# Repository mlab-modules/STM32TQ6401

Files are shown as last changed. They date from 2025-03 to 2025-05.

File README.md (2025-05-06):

# STM32TQ6401 - Universal TQFP64 STM32 Microcontroller Module

The STM32TQ6401 is a universal microcontroller module designed for STM32 MCUs in TQFP64 packages. It offers a flexible platform for both development and deployment, with support for a wide range of STM32 devices and power configurations.

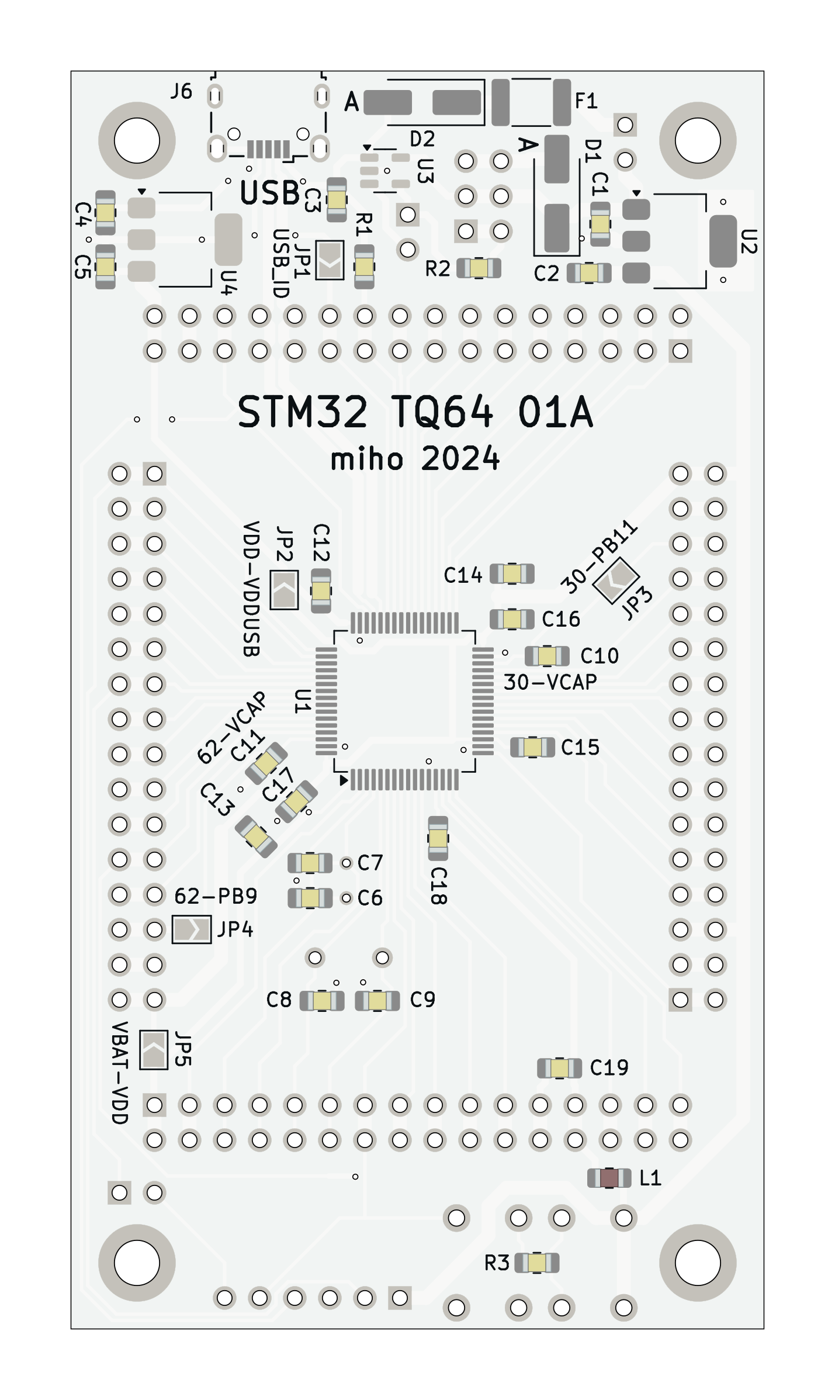
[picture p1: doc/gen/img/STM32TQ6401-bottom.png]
STM32TQ6401 module bottom

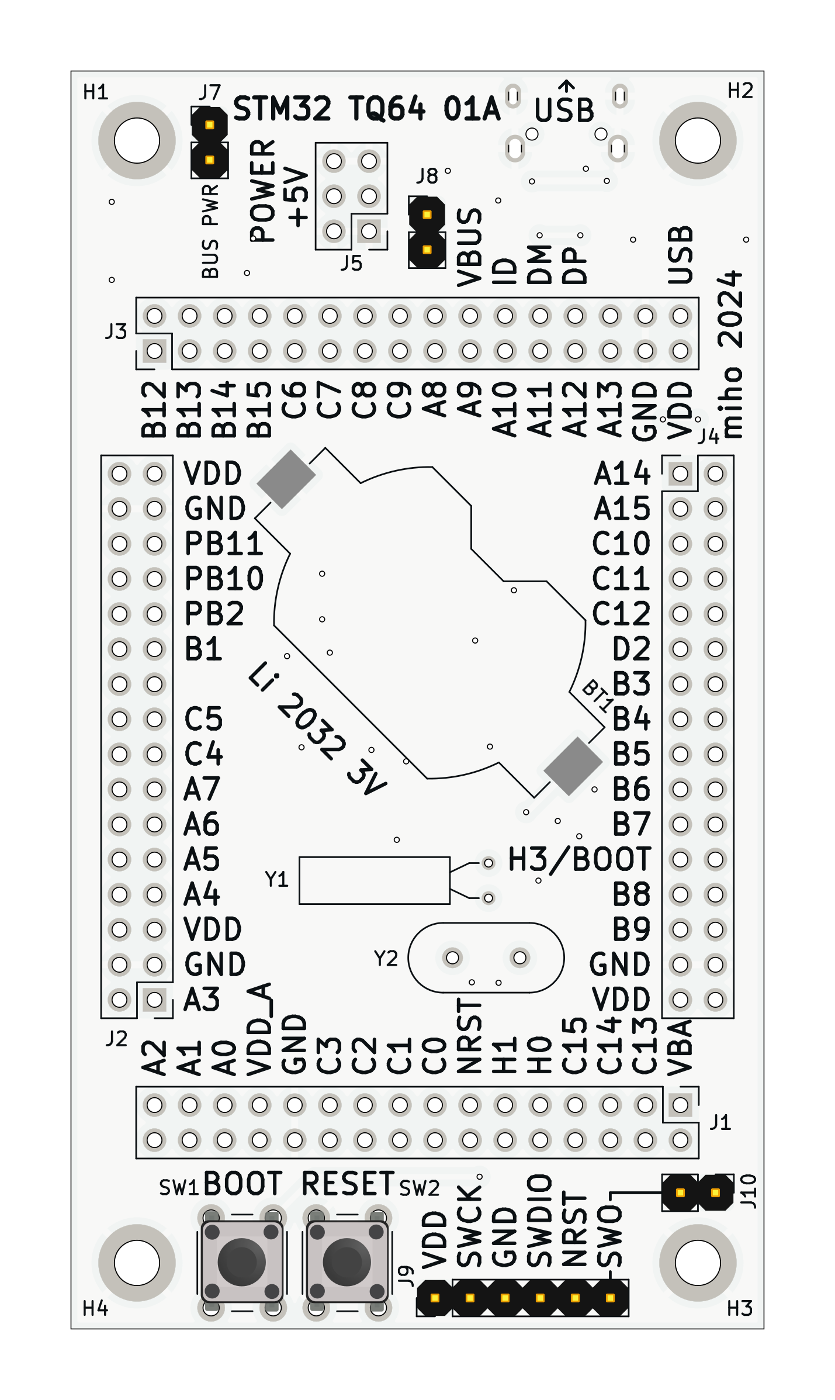
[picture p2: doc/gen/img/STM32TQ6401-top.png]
STM32TQ6401 module top


## Features

- Compatible with most STM32 MCUs in TQFP64 package (see note in schematics for exceptions)
- Direct battery operation from a CR2032 cell
- USB-C connector for both programming and external power input
- Standard MLAB pin headers for module interconnection to other MLAB modules
- Onboard 32.768 kHz and 16 MHz crystal oscillators for RTC and system clock
- Multiple LDO regulators providing 3.3V from USB or external 5V input
- USB power switch (TPS2051B) for host/device support
- Boot and reset buttons, debug header (SWD), and optional VCAP configuration

## Power Supply

- **Battery Operation:** Directly powered by a CR2032 cell; suitable for ultra-low power STM32 MCUs
- **USB Power:** Supplied through USB-C connector; LDO regulator converts 5V to 3.3V
- **External Power Input:** 2.6 V to 5.2 V via dedicated jumper or header

## Connectivity

- USB-C for firmware upload and serial communication
- SWD (Serial Wire Debug) header for in-circuit debugging
- MLAB standard headers for full I/O access

## Clock Sources

- **Y1:** 32.768 kHz crystal for RTC
- **Y2:** 16 MHz crystal for system clock

### Incompatible STM32 Devices
Some STM32 MCUs are not compatible with this module due to VCAP or other special pin requirements. These include (but are not limited to):

- STM32F030R4Tx, STM32F405RGTx, STM32H7xxRxTx
- STM32G4xxRxTx, STM32L5xxRxTxQ, STM32U5xxRxTxQ

Refer to schematic details for a complete list of incompatible devices.

### Pin Variants

Special attention is required for the following pins due to variant functions:

- VBAT / VLCD
- VCAP / VDDUSB
- BOOT0 / PH3

Refer to MCU datasheets and the module schematic for proper configuration.

## Mounting

- Four 3mm MLAB mounting holes for mechanical stability

## Schematic

For detailed pinout, power configuration, and compatibility, refer to the [STM32TQ6401A schematic](/doc/gen/STM32TQ6401-schematic.pdf).

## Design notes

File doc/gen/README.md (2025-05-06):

# PCB

Board size: 50.29x91.19 mm (1.98x3.59 inches)

- This is the size of the rectangle that contains the board
- Thickness: 1.6 mm (63 mils)
- Material: FR4
- Finish: HAL lead-free
- Layers: 2
- Copper thickness: 35 µm

Solder mask: TOP / BOTTOM

- Color: Green

Silk screen: TOP / BOTTOM

- Color: White

Stackup:

| Name | Type | Color | Thickness [µm]| Material | Er | Loss tan |
|---|---|---|---|---|---|---|
| F.SilkS | Top Silk Screen | White | | | | |
| F.Paste | Top Solder Paste | | | | | |
| F.Mask | Top Solder Mask | Green | 10 | | | |
| F.Cu | copper | | 35 | | | |
| dielectric 1 | core | | 1510 | FR4 | 4.5 | 0.020 |
| B.Cu | copper | | 35 | | | |
| B.Mask | Bottom Solder Mask | Green | 10 | | | |
| B.Paste | Bottom Solder Paste  | | | | | |
| B.SilkS | Bottom Silk Screen | White | | | | |

# Important sizes

Clearance: 0.2 mm (8 mils)

Track width: 0.25 mm (10 mils)

- By design rules: 0.25 mm (10 mils)

Drill: 0.4 mm (16 mils)

- Vias: 0.4 mm (16 mils) [Design: 0.4 mm (16 mils)]
- Pads: 0.6 mm (24 mils)
- The above values are real drill sizes, they add 0.1 mm (4 mils) to plated holes (PTH)

Via: 0.6/0.3 mm (24/12 mils)

- By design rules: 0.5/0.3 mm (20/12 mils)
- Micro via: yes [0.2/0.1 mm (8/4 mils)]
- Buried/blind via: yes
- Total: 34 (thru: 34 buried/blind: 0 micro: 0)

Outer Annular Ring: 0.1 mm (4 mils)

- By design rules: 0.2 mm (8 mils)

Eurocircuits class: 6C
- Using min drill 0.35 mm for an OAR of 0.13 mm

# General stats

Components count: (SMD/THT)

- Top: 1/13 (SMD + THT)
- Bottom: 31/0 (SMD)

Defined tracks:

- 0.25 mm (10 mils)
- 0.25 mm (10 mils)
- 0.3 mm (12 mils)
- 0.4 mm (16 mils)
- 0.5 mm (20 mils)
- 0.8 mm (31 mils)
- 1.0 mm (39 mils)

Used tracks:

- 0.25 mm (10 mils) (310) defined: yes
- 0.3 mm (12 mils) (2) defined: yes
- 0.4 mm (16 mils) (27) defined: yes
- 0.5 mm (20 mils) (118) defined: yes
- 0.8 mm (31 mils) (18) defined: yes
- 1.0 mm (39 mils) (114) defined: yes

Defined vias:

Used vias:

- 0.6/0.3 mm (24/12 mils) (Count: 34, Aspect: 2.7 A) defined: no

Holes (excluding vias):

- 0.5 mm (20 mils) (2)
- 0.8 mm (31 mils) (4)
- 1.0 mm (39 mils) (146)
- 1.1 mm (43 mils) (8)
- 3.2 mm (126 mils) (4)

Oval holes:

- 0.55x1.2 mm (22x47 mils) (2)
- 0.85x1.4 mm (33x55 mils) (2)

Drill tools (including vias and computing adjusts and rounding):

- 0.4 mm (16 mils) (34)
- 0.6 mm (24 mils) (2)
- 0.65 mm (26 mils) (2)
- 0.8 mm (31 mils) (2)
- 0.9 mm (35 mils) (2)
- 0.95 mm (37 mils) (2)
- 1.1 mm (43 mils) (146)
- 1.2 mm (47 mils) (8)
- 3.3 mm (130 mils) (4)

Solder paste stats:

Using a paste with 87.75 % alloy, that has an specific gravity for the alloy of 7.4 g/cm³
and 1.0 g/cm³ for the flux. This paste has an specific gravity of  4.15 g/cm³.

The stencil thickness is  0.12 mm.

| Side | Pads with paste | Area [mm²] | Paste [g] |
|---|---|---|---|
| Top | 2 | 18.20 | 0.09 |
| Bottom | 134 | 177.38 | 0.88 |
| Total  | 136 | 195.58 | 0.97 |

Note: this is just an approximation to the theoretical value. Margins of the solder mask and waste aren't computed.

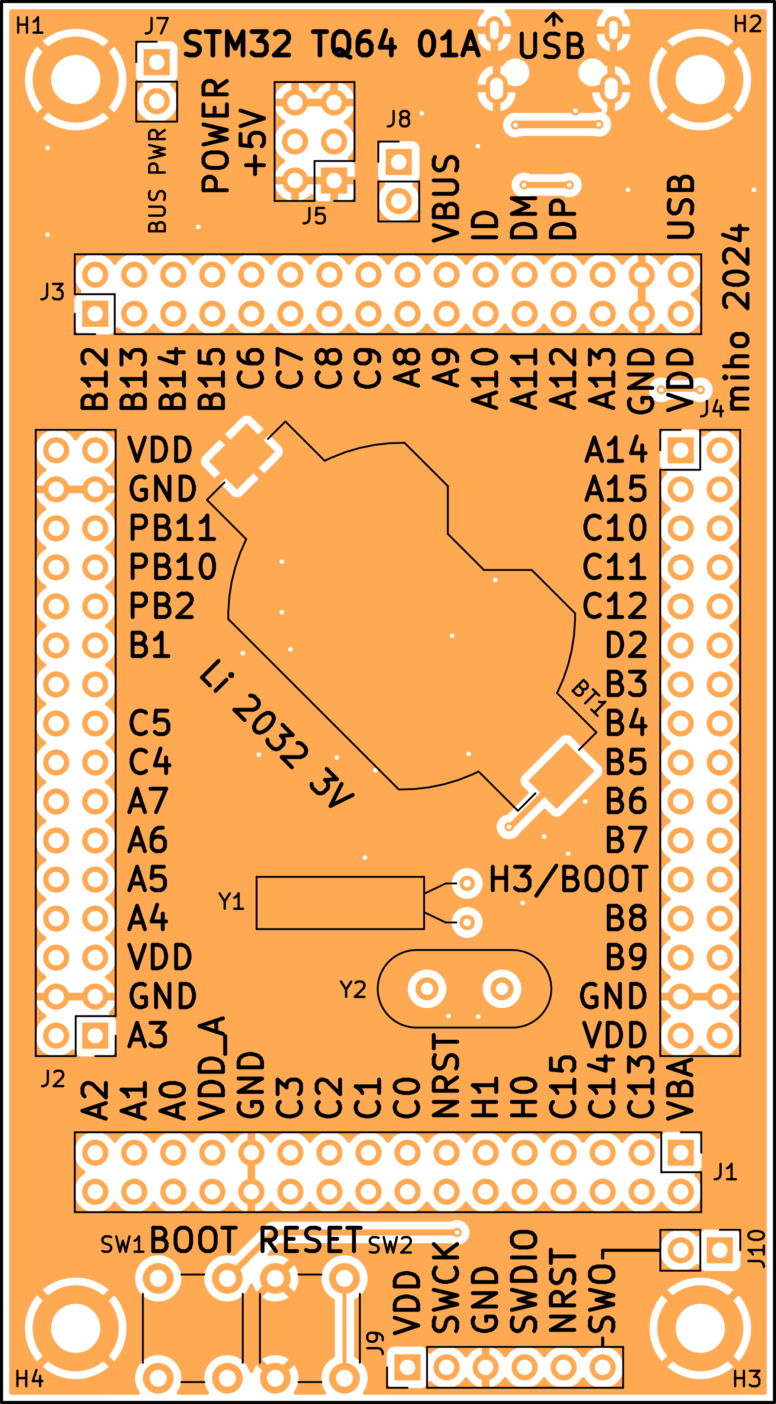
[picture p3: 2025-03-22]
hw/CAM_DOC/STM32TQ6401A_TOP.png

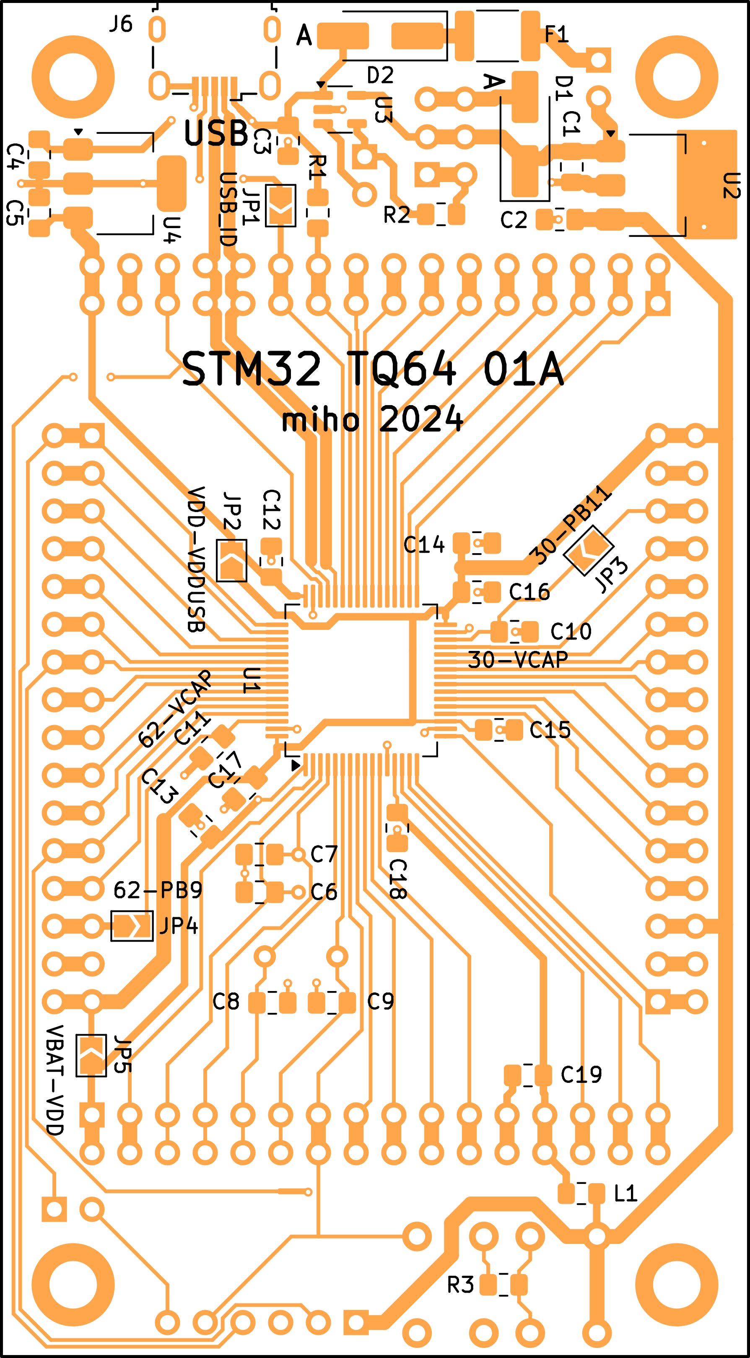
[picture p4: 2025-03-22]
hw/CAM_DOC/STM32TQ6401A_BOT.png

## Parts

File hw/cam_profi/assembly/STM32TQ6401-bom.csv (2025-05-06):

Component | Description | Part | References | Value | Footprint | Quantity Per PCB | Datasheet | sim.device | sim.pins
1 | Single-cell battery | Battery_Cell | BT1 | 2032 | BatteryHolder_Renata_SMTU2032 | 1 | https://cz.mouser.com/datasheet/2/346/renata_smtu2032-lf-1201277.pdf
2 | C0805 | C | C8C9 | 10pF | C_0805_2012Metric_Pad1.18x1.45mm_HandSolder | 2 | ~
3 | C0805 | C | C6C7 | 22pF | C_0805_2012Metric_Pad1.18x1.45mm_HandSolder | 2 | ~
4 | C0805 | C | C1C2C4C5C12C13C15C16C17C18 | 100nF | C_0805_2012Metric_Pad1.18x1.45mm_HandSolder | 10 | ~
5 | C0805 | C | C19 | 2u2 | C_0805_2012Metric_Pad1.18x1.45mm_HandSolder | 1 | ~
6 | C0805 | C | C14 | 10uF | C_0805_2012Metric_Pad1.18x1.45mm_HandSolder | 1 | ~
7 | C0805 | C | C3C10C11 | 2u2/10V | C_0805_2012Metric_Pad1.18x1.45mm_HandSolder | 3 | ~
8 | 30V/1A/SMA | D_Schottky | D2 | B130-13-F | D_SMA_Handsoldering | 1 | ~
9 | 1A/SMA | D | D1 | M7-DCO | D_SMA_Handsoldering | 1 | ~ | D | 1=K 2=A
10 | 1A/F1812 | Polyfuse | F1 | Polyfuse | Fuse_1812_4532Metric_Pad1.30x3.40mm_HandSolder | 1 | ~
11 | Header connector, single row, 01x02, script generated | JUMP_01x02_M | J7J8J10 | JUMP_01x02 | PinHeader_1x02_P2.54mm_Vertical | 3 | ~
12 | Header connector, single row, 01x06, script generated | STM32_SWD_JUMP6 | J9 | JUMP_01x06 | PinHeader_1x06_P2.54mm_Vertical | 1 | ~
13 | Header connector, double row, 02x16,, script generated | JUMP_02x16_M_connected_L | J1J2J3J4 | JUMP_02x16 | PinHeader_2x16_P2.54mm_Vertical | 4 | ~
14 | Header connector, double row, 02x03,, script generated | JUMP_02x03_M_connected_R | J5 | JUMP_2x3 | PinHeader_2x03_P2.54mm_Vertical | 1 | ~
15 | USB Micro Type B | USB_B_Micro | J6 | Wuerth_629105150521 | USB_Micro-B_Wuerth_629105150521 | 1 | ~
16 | L0805 | FerriteBead_Small | L1 | 100R | L_0805_2012Metric_Pad1.15x1.40mm_HandSolder | 1 | ~
17 | R0805 | R | R1R2 | 1k | C_0805_2012Metric_Pad1.18x1.45mm_HandSolder | 2 | ~
18 | Resistor | R | R3 | 10k | C_0805_2012Metric_Pad1.18x1.45mm_HandSolder | 1 | ~
19 | Push button switch, generic, two pins | SW_Push | SW1SW2 | SW_Push | SW_PUSH_6mm | 2 | ~
20 | SOT223 | MCP1825S | U2 | MCP1825S-3302E/DB | SOT-223-3_TabPin2 | 1 | http://ww1.microchip.com/downloads/en/devicedoc/22056b.pdf
21 | STMicroelectronics Arm Cortex-M33 MCU, 128KB flash, 32KB RAM, 250 MHz, 49 GPIO, LQFP64 | STM32H503RBTx | U1 | STM32_UNIVERSAL | LQFP-64_10x10mm_P0.5mm | 1 | https://www.st.com/resource/en/datasheet/stm32h503rb.pdf
22 | Two pin crystal | Crystal | Y2 | 16MHz | Crystal_HC49-U_Vertical | 1 | ~
23 | Two pin crystal | Crystal | Y1 | 32768Hz | Crystal_AT310_D3.0mm_L10.0mm_Horizontal | 1 | ~

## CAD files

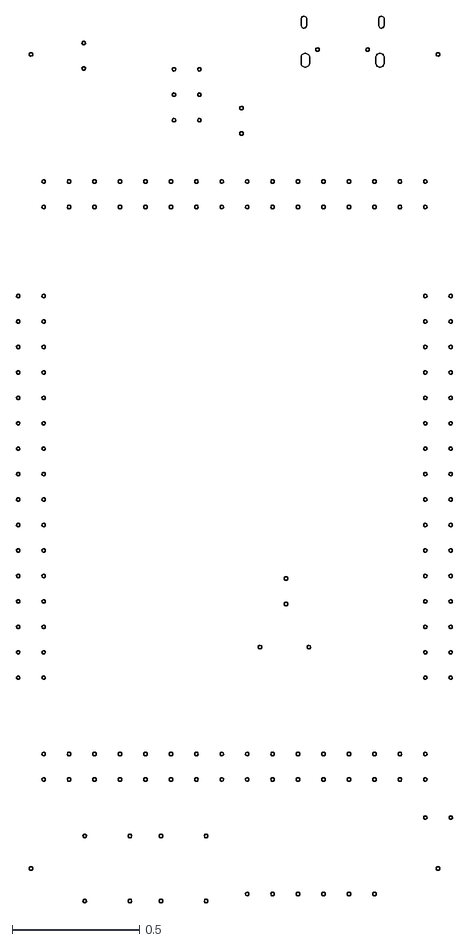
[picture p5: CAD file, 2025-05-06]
doc/gen/dxf/STM32TQ6401-User_9.dxf
1.71 x 3.49

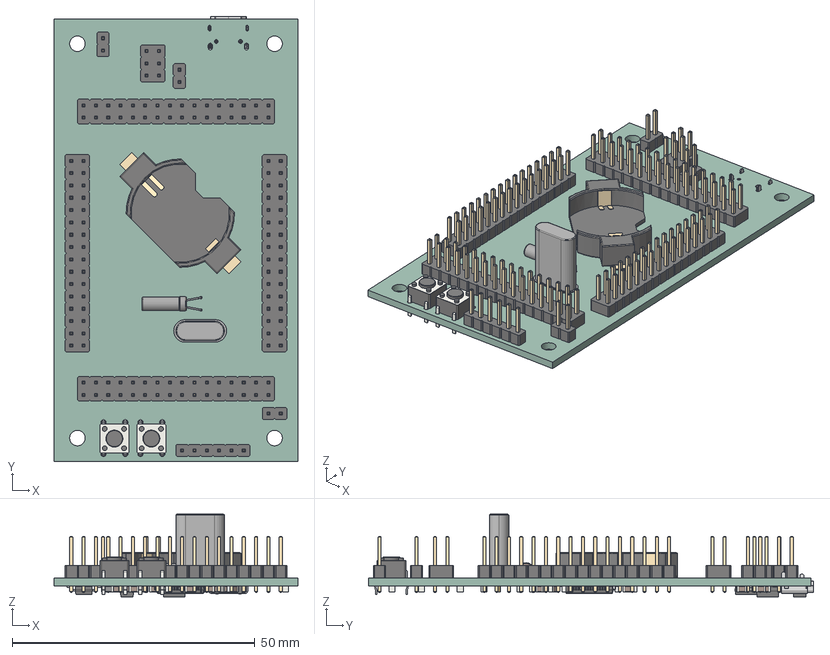
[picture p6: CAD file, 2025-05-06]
doc/gen/STM32TQ6401.step
50.3 x 91.7 x 17.0 mm
PinHeader_2x16_P254mm_Vertical x 4
PinHeader_2x03_P254mm_Vertical
PinHeader_1x02_P254mm_Vertical x 3
Crystal_HC49-U_Vertical
PinHeader_1x06_P254mm_Vertical
Keystone_1058_1x2032
AT310_Horizontal
SW_PUSH_6mm x 2
C_0805_2012Metric x 22
D_SMA x 2
SOT_223
L_0805_2012Metric
LQFP_64_10x10mm_P05mm
miniSMDC150F
kibot_p9uvynsr_PCB

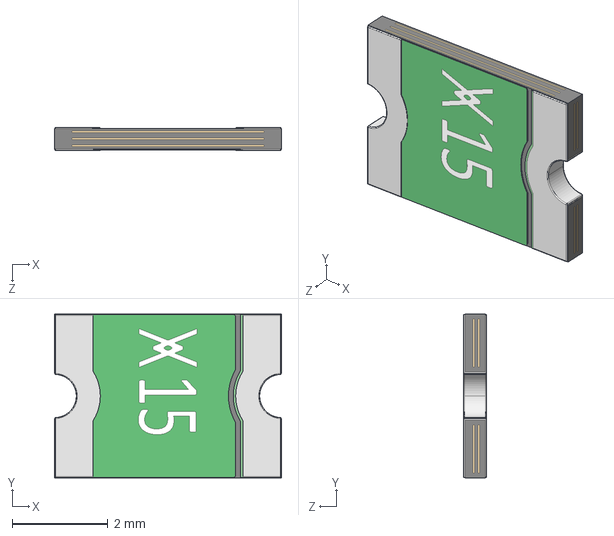
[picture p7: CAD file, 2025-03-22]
hw/sch_pcb/KiCAD_LIB/3D/miniSMDC150F.STEP
4.73 x 3.41 x 0.48 mm

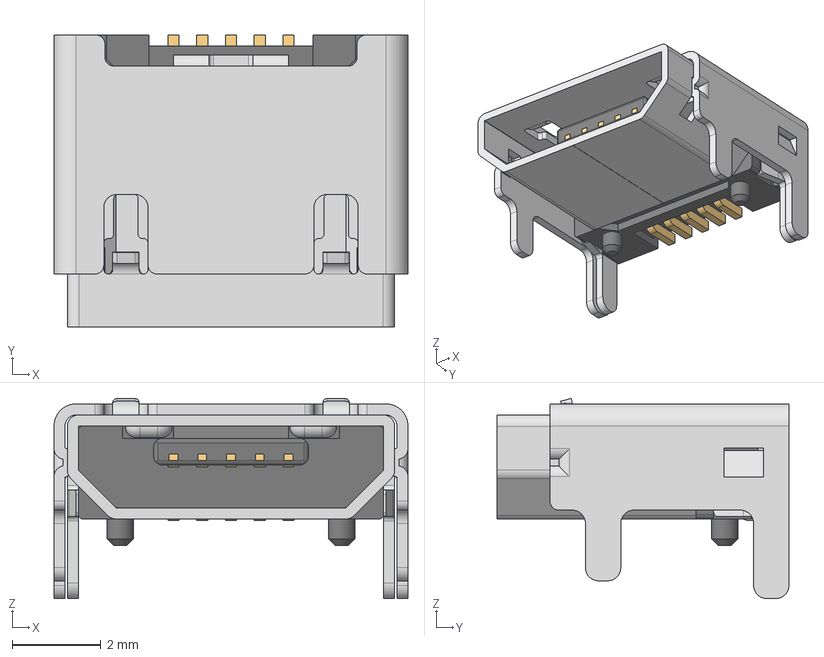
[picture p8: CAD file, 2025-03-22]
hw/sch_pcb/KiCAD_LIB/3D/WURTH_629105150521.stp
8.00 x 6.60 x 4.52 mm
629105150521_Housing
629105150521_Pin1 x 4
629105150521_Pin2
629105150521_Shielding2
629105150521_Shielding

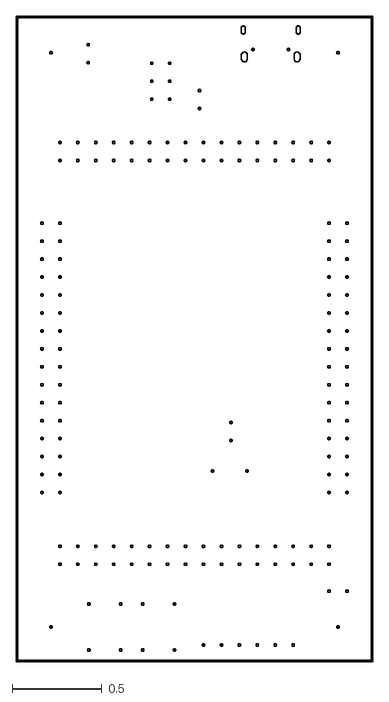
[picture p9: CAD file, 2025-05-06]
doc/gen/dxf/STM32TQ6401-Edge_Cuts.dxf
1.99 x 3.60

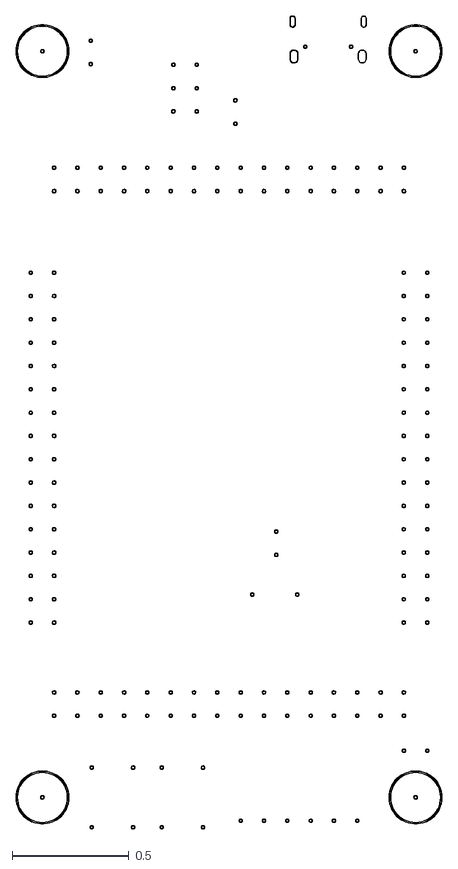
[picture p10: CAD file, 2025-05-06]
doc/gen/dxf/STM32TQ6401-User_Comments.dxf
1.83 x 3.49

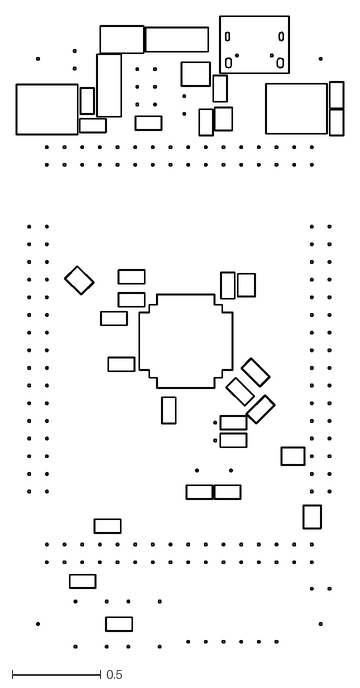
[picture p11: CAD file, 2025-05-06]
doc/gen/dxf/STM32TQ6401-B_Courtyard.dxf
1.85 x 3.58

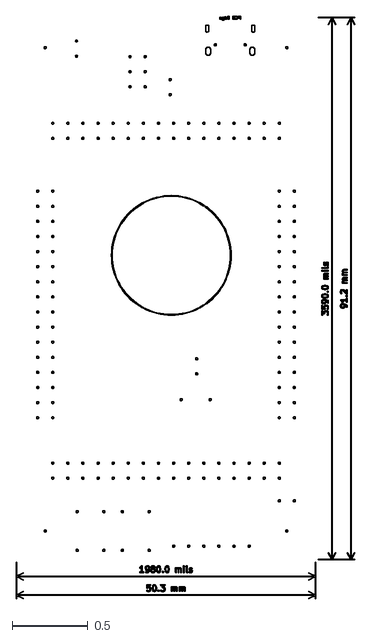
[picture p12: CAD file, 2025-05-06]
doc/gen/dxf/STM32TQ6401-User_Drawings.dxf
2.24 x 3.86

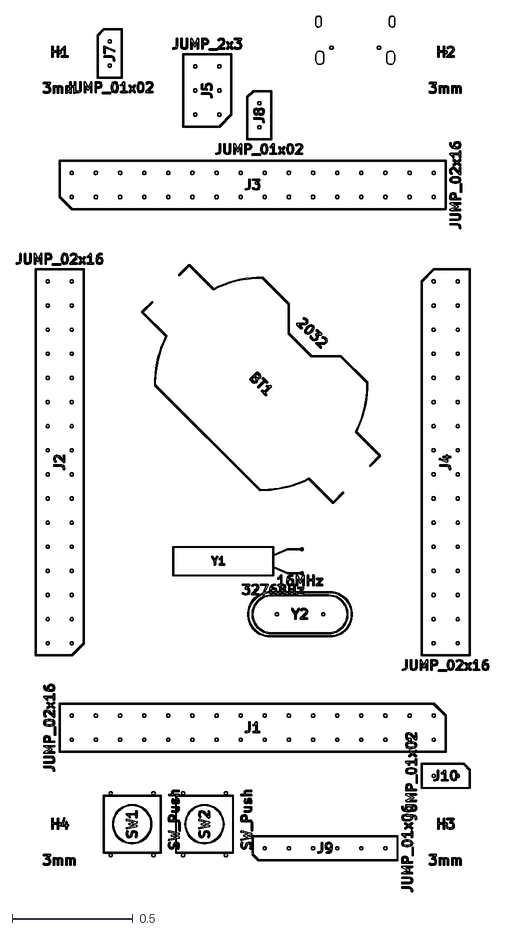
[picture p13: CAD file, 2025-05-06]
doc/gen/dxf/STM32TQ6401-F_Fab.dxf
1.96 x 3.63

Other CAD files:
doc/gen/dxf/STM32TQ6401-F_Adhesive.dxf
doc/gen/dxf/STM32TQ6401-B_Adhesive.dxf
doc/gen/dxf/STM32TQ6401-B_Cu.dxf
doc/gen/dxf/STM32TQ6401-B_Fab.dxf
doc/gen/dxf/STM32TQ6401-B_Mask.dxf
doc/gen/dxf/STM32TQ6401-B_Paste.dxf
doc/gen/dxf/STM32TQ6401-B_Silkscreen.dxf
doc/gen/dxf/STM32TQ6401-F_Courtyard.dxf
doc/gen/dxf/STM32TQ6401-F_Cu.dxf
doc/gen/dxf/STM32TQ6401-F_Mask.dxf
doc/gen/dxf/STM32TQ6401-F_Paste.dxf
doc/gen/dxf/STM32TQ6401-F_Silkscreen.dxf

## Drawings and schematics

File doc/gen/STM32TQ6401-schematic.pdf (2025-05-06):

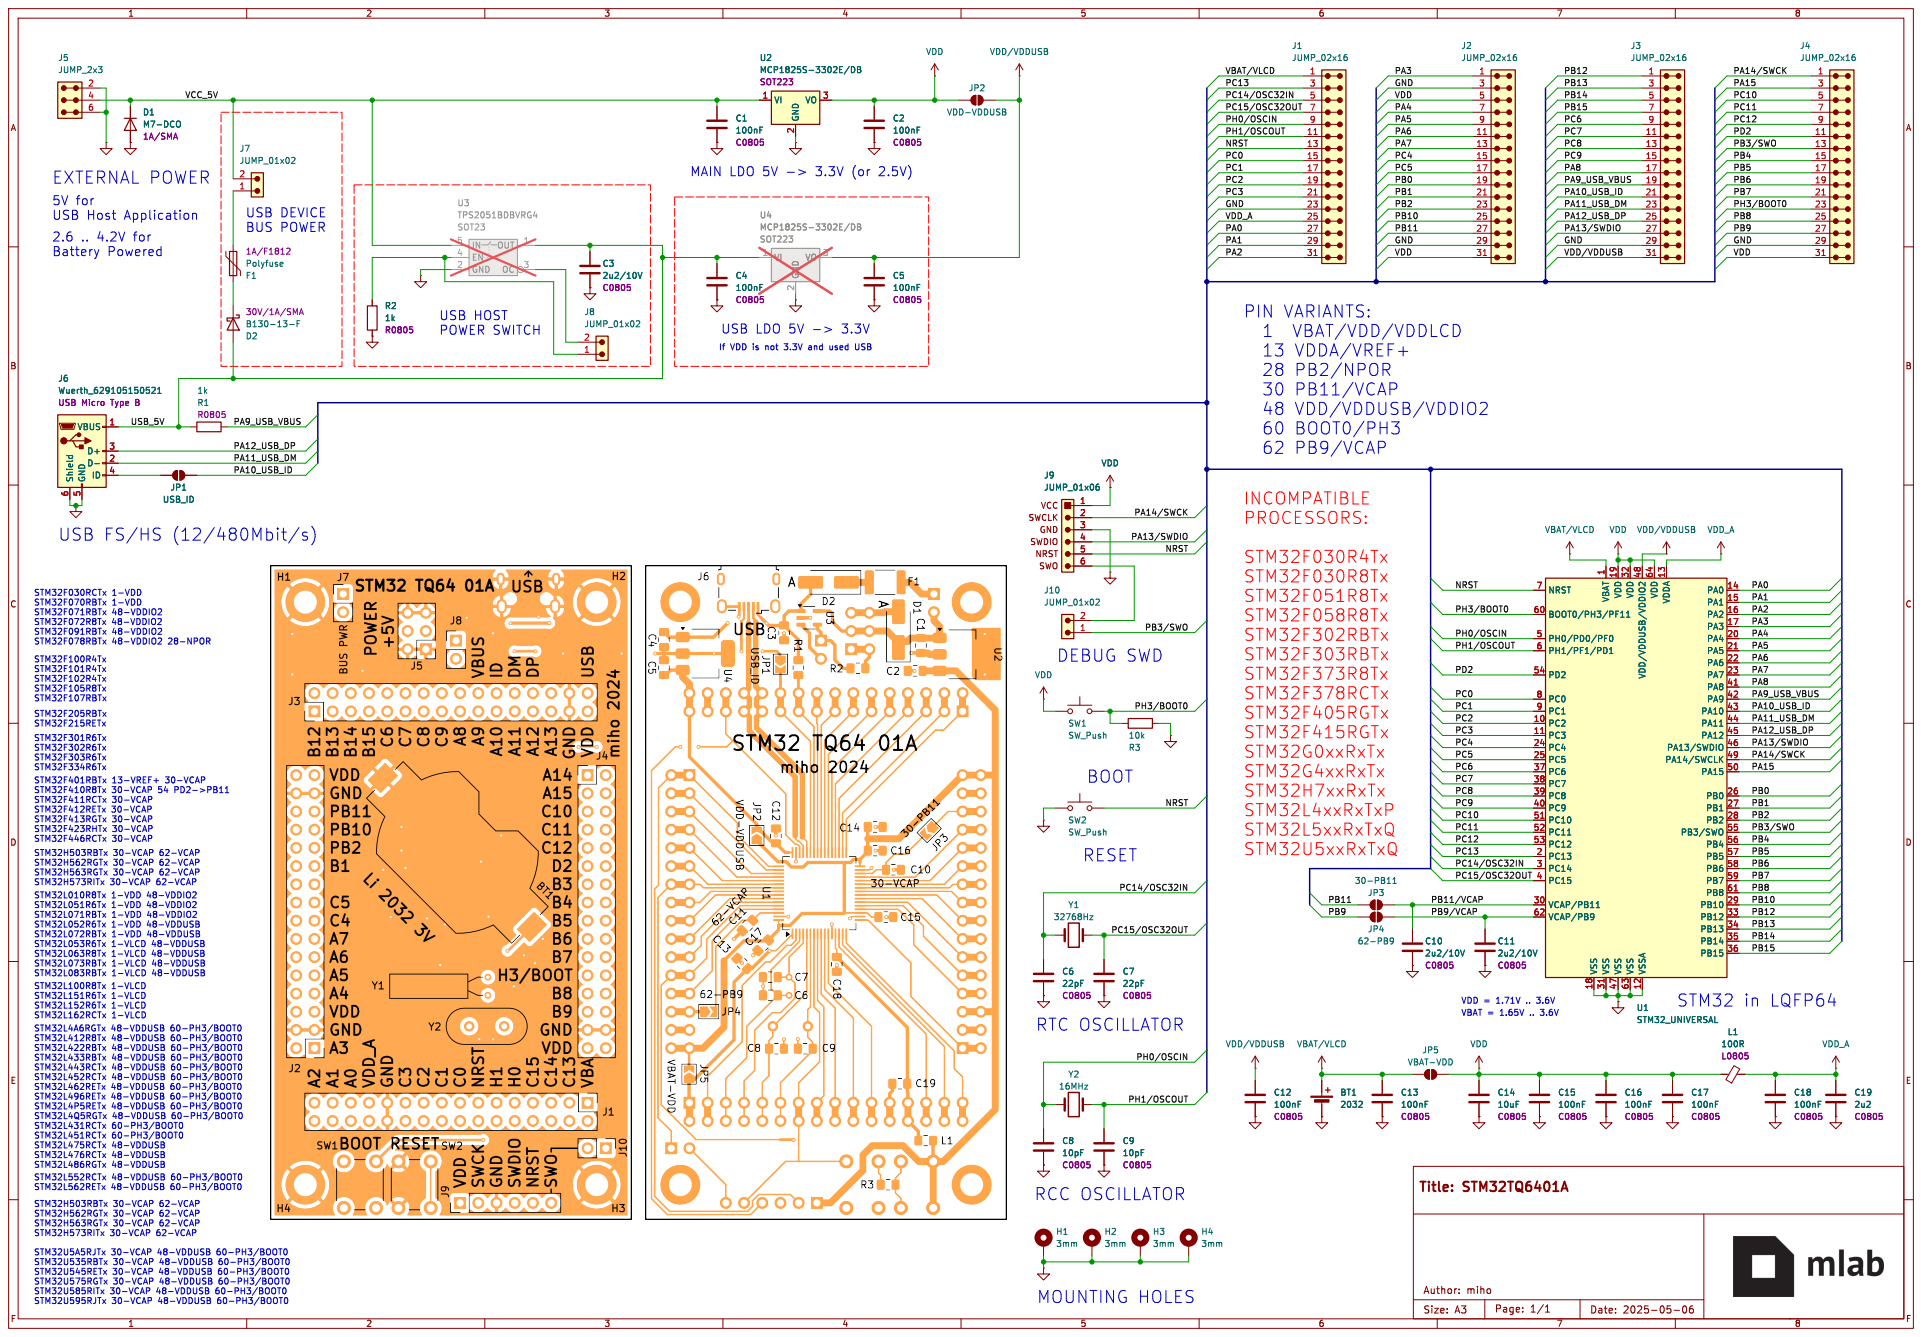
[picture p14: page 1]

If VDD is not 3.3V and used USB

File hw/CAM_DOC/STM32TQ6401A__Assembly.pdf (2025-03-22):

## A USB

# L1 U1 F1 C16 C9

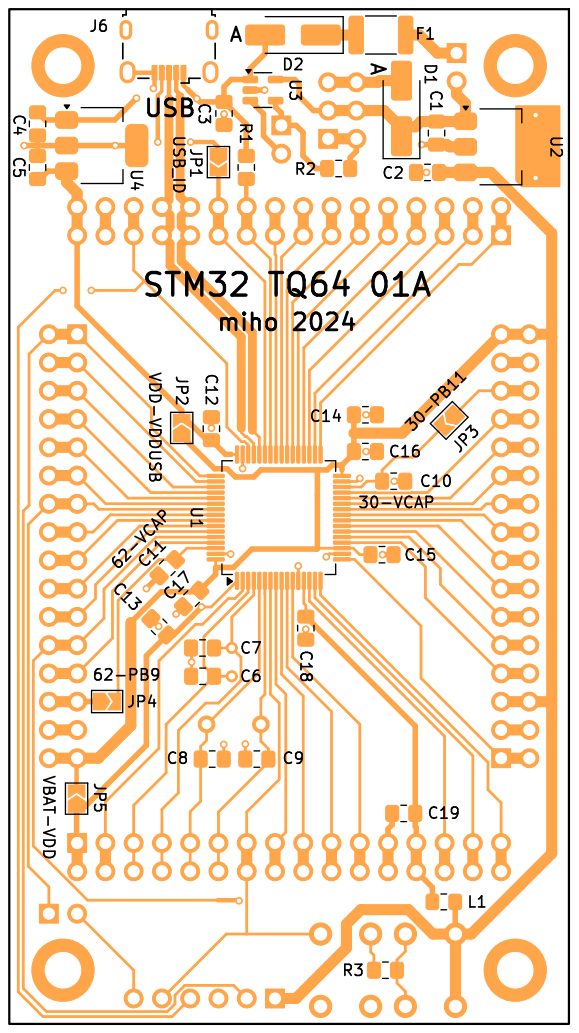
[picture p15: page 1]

B7 PB11 C4 B1A¹ A7 | A14 H¹ ⁺⁵V | A15 GND C⁶ | VBA VDD BUS PWR | C¹
C5 | GND B¹⁵ BOOT | B4 DM | C¹³

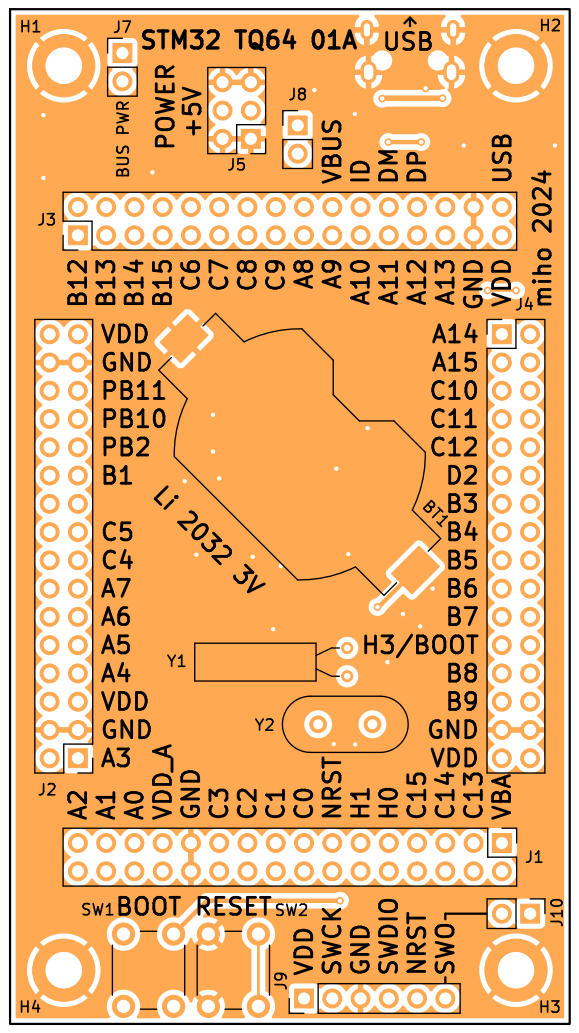
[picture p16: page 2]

USB NRST VDD GND C15 A12 SWCK

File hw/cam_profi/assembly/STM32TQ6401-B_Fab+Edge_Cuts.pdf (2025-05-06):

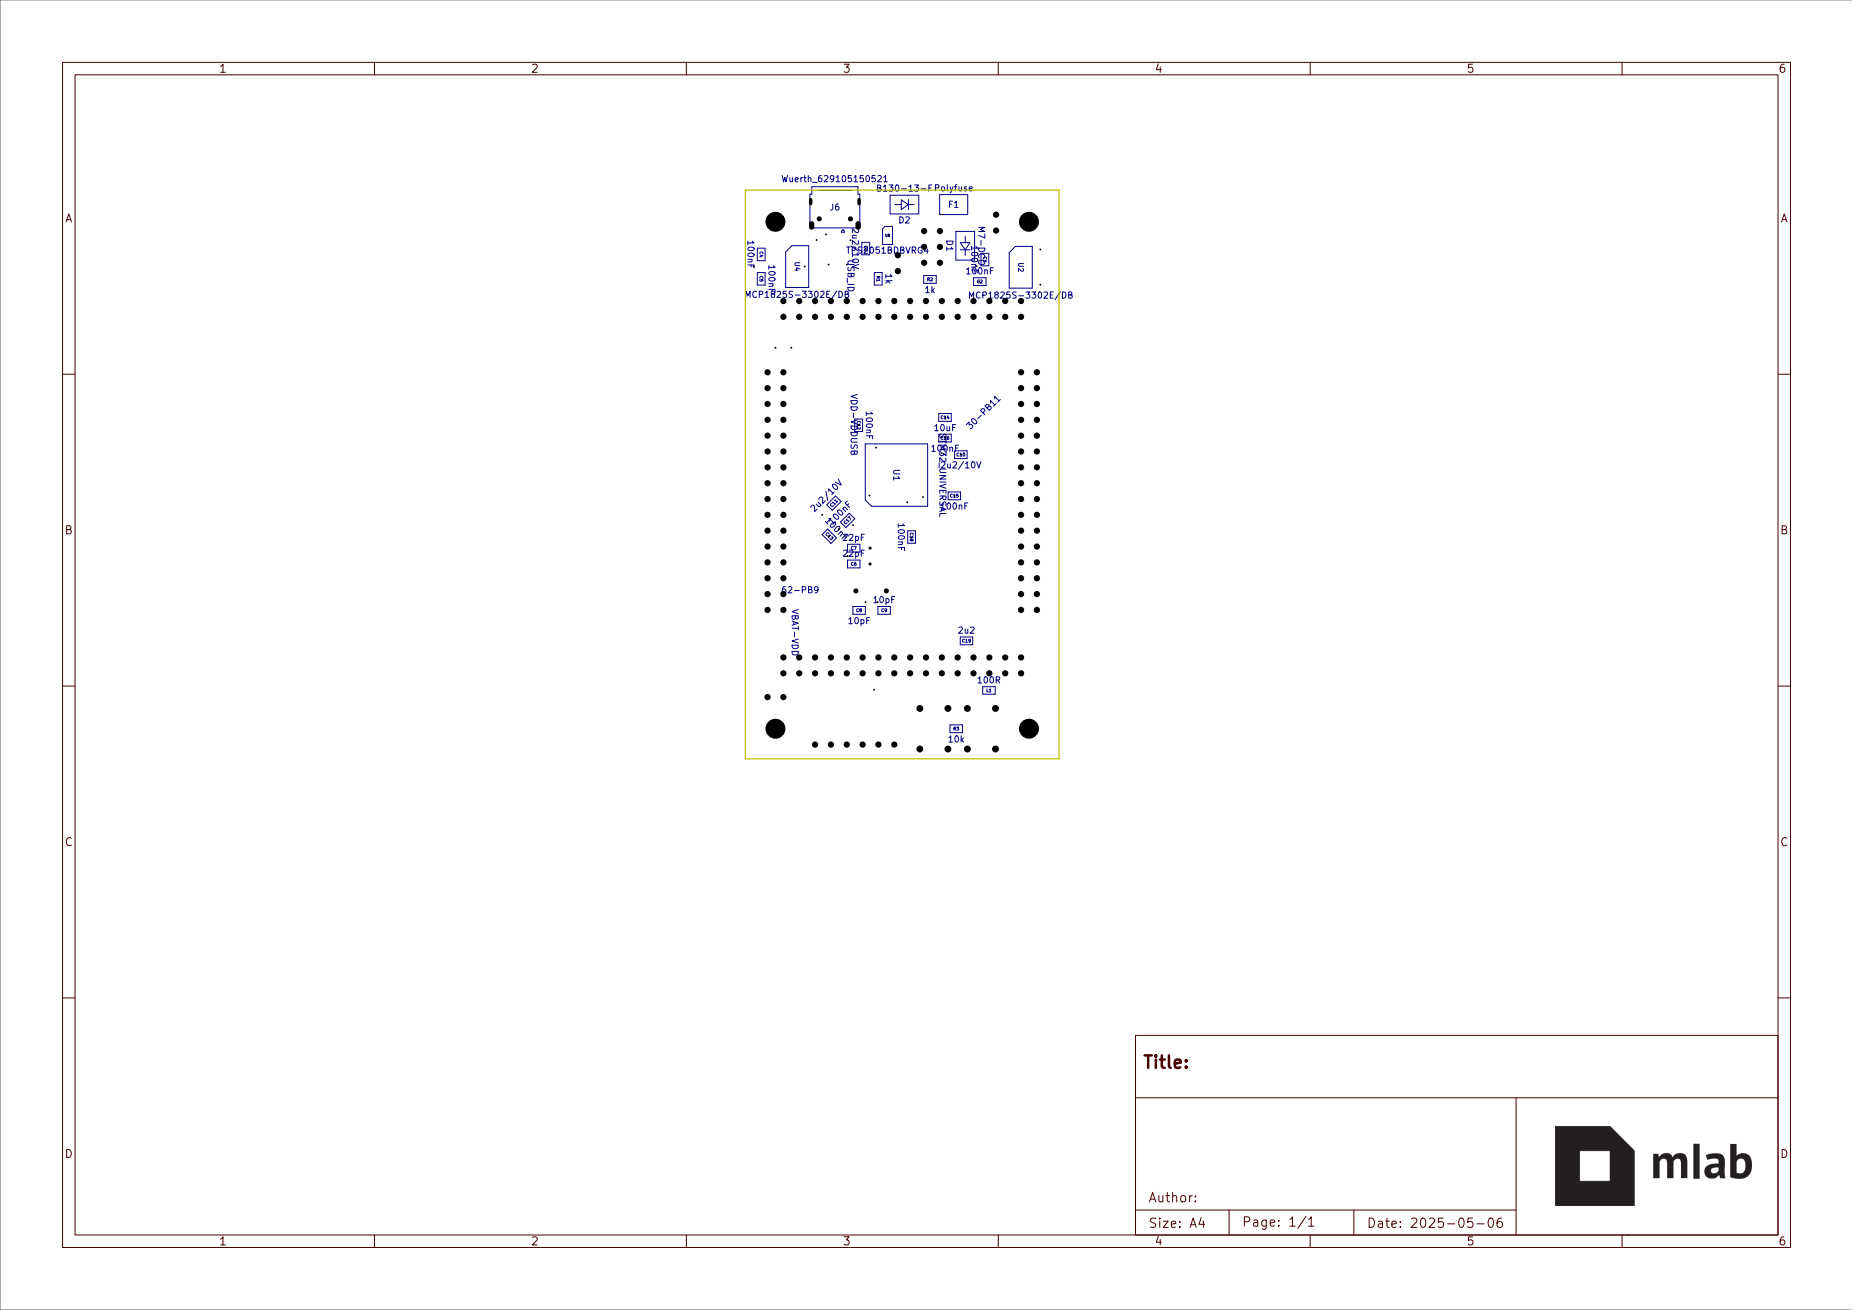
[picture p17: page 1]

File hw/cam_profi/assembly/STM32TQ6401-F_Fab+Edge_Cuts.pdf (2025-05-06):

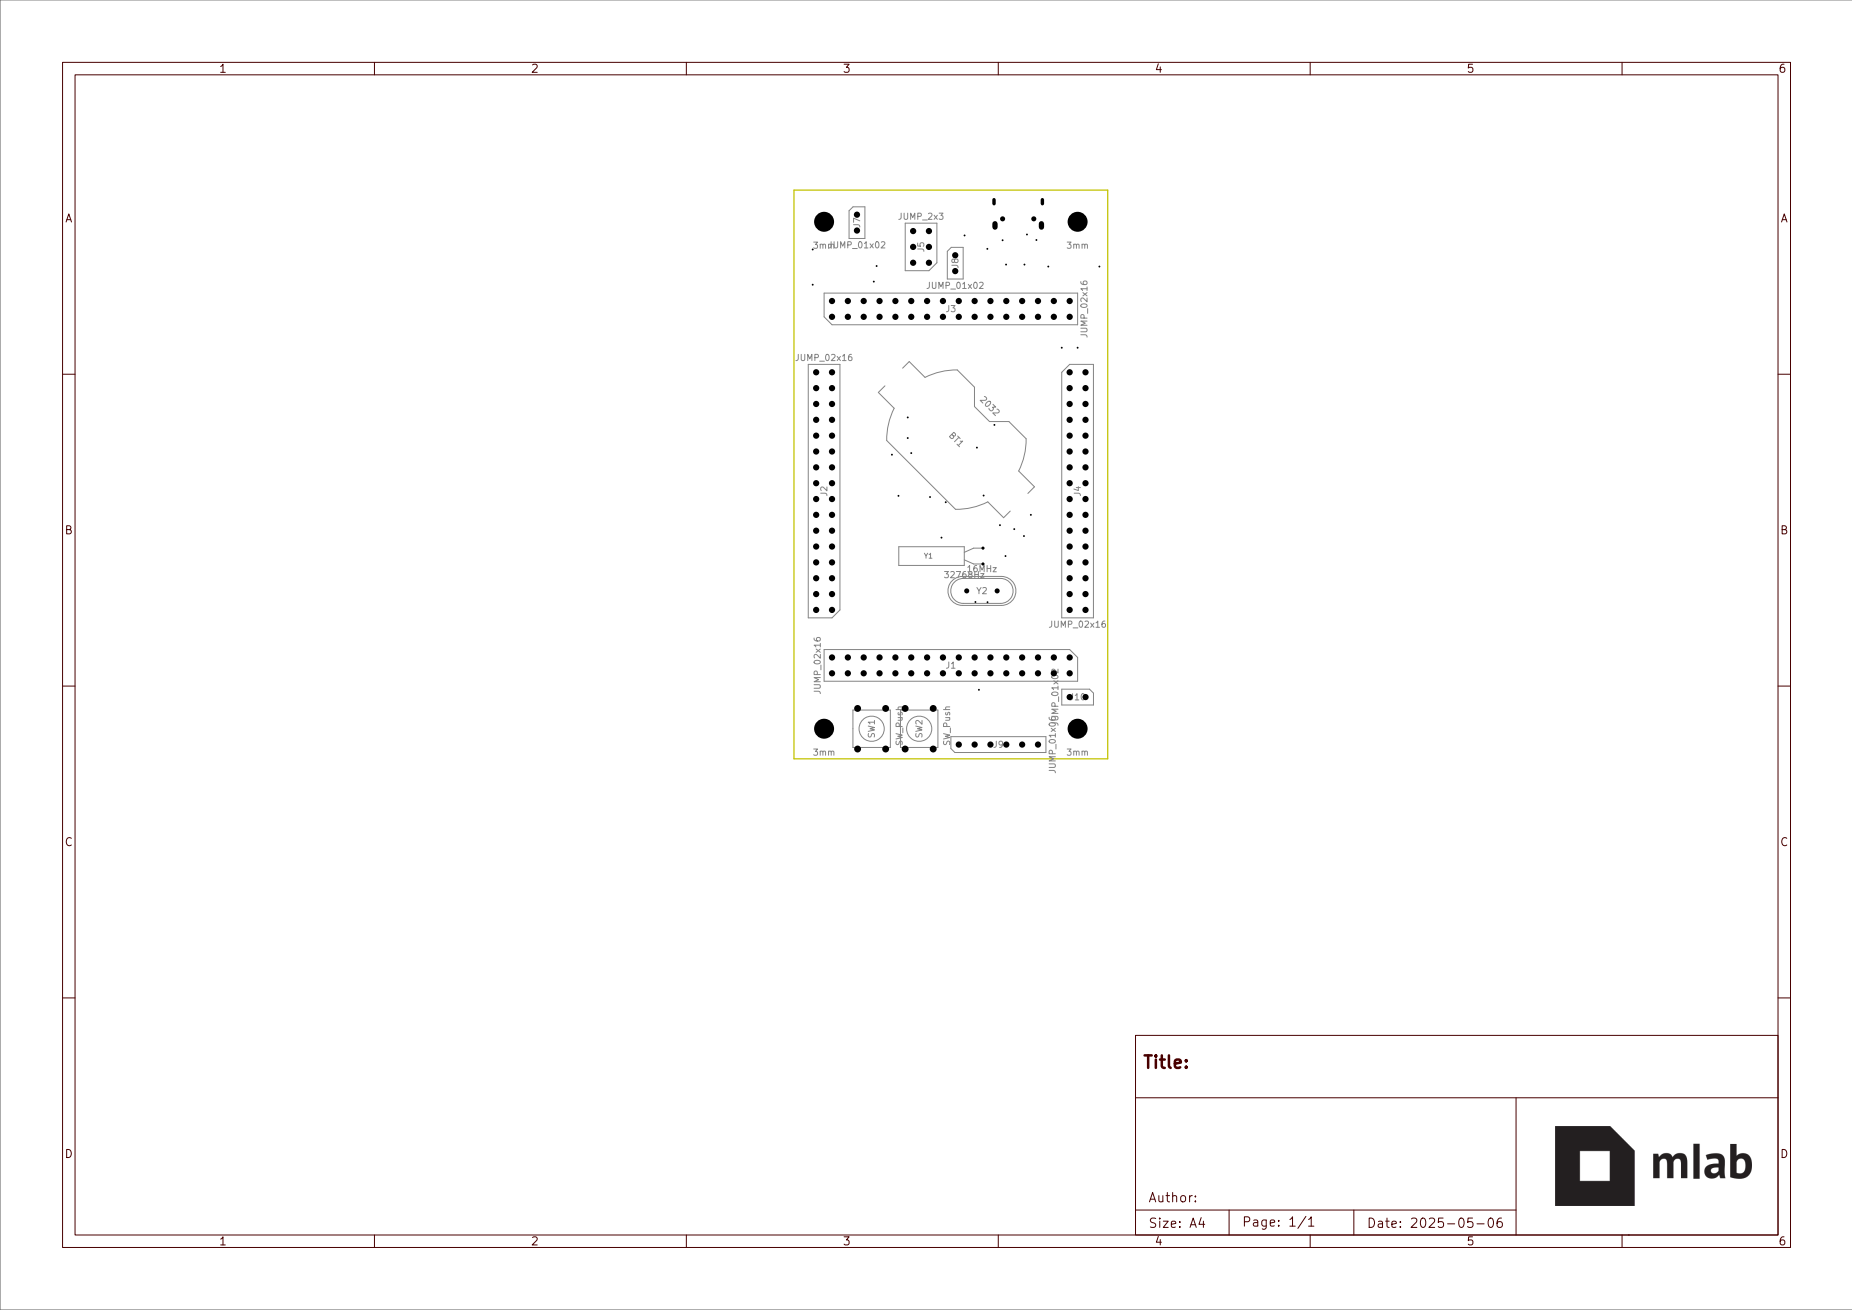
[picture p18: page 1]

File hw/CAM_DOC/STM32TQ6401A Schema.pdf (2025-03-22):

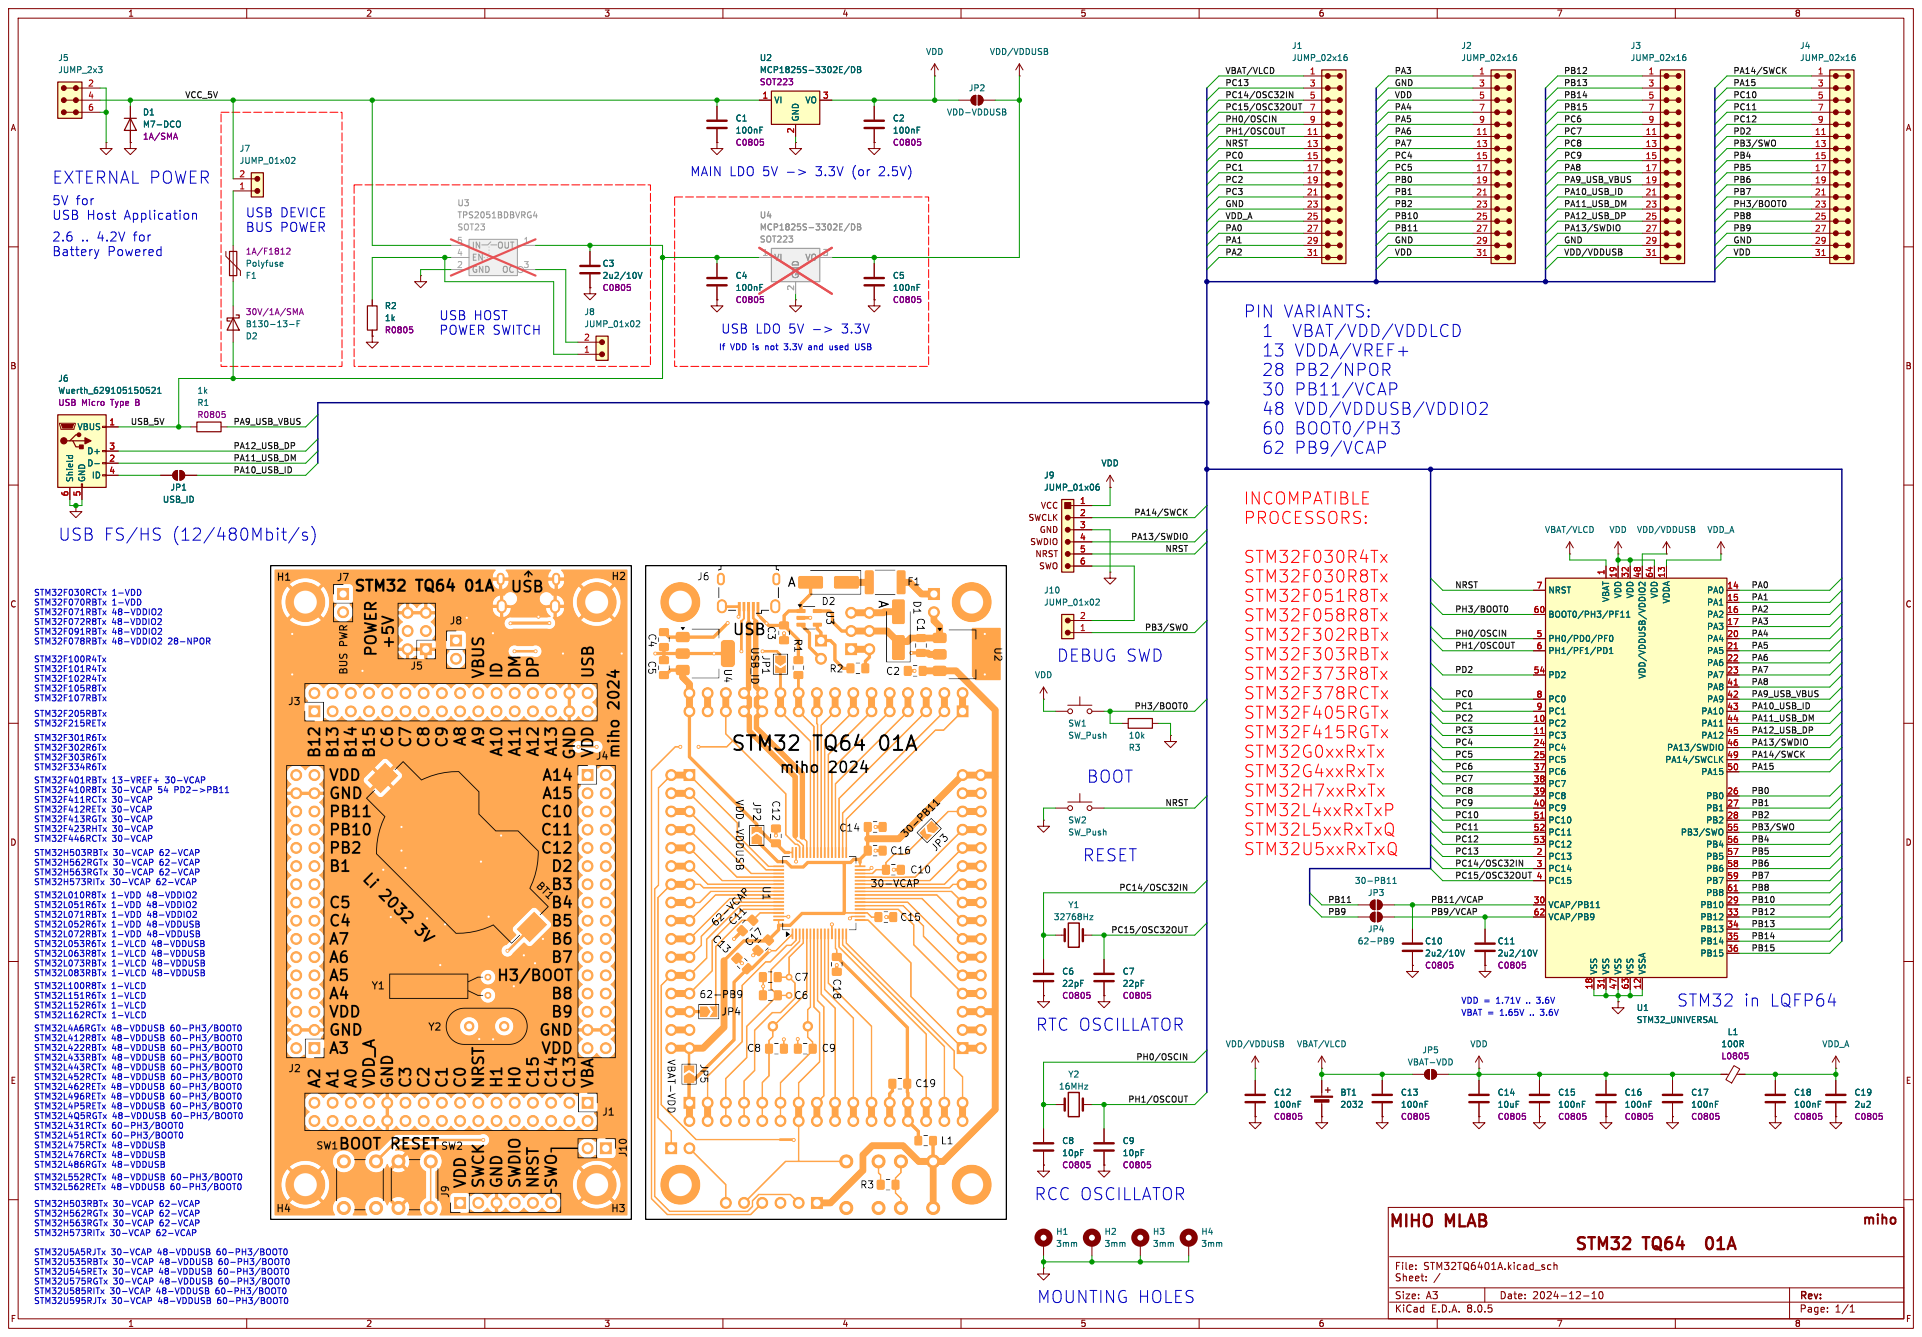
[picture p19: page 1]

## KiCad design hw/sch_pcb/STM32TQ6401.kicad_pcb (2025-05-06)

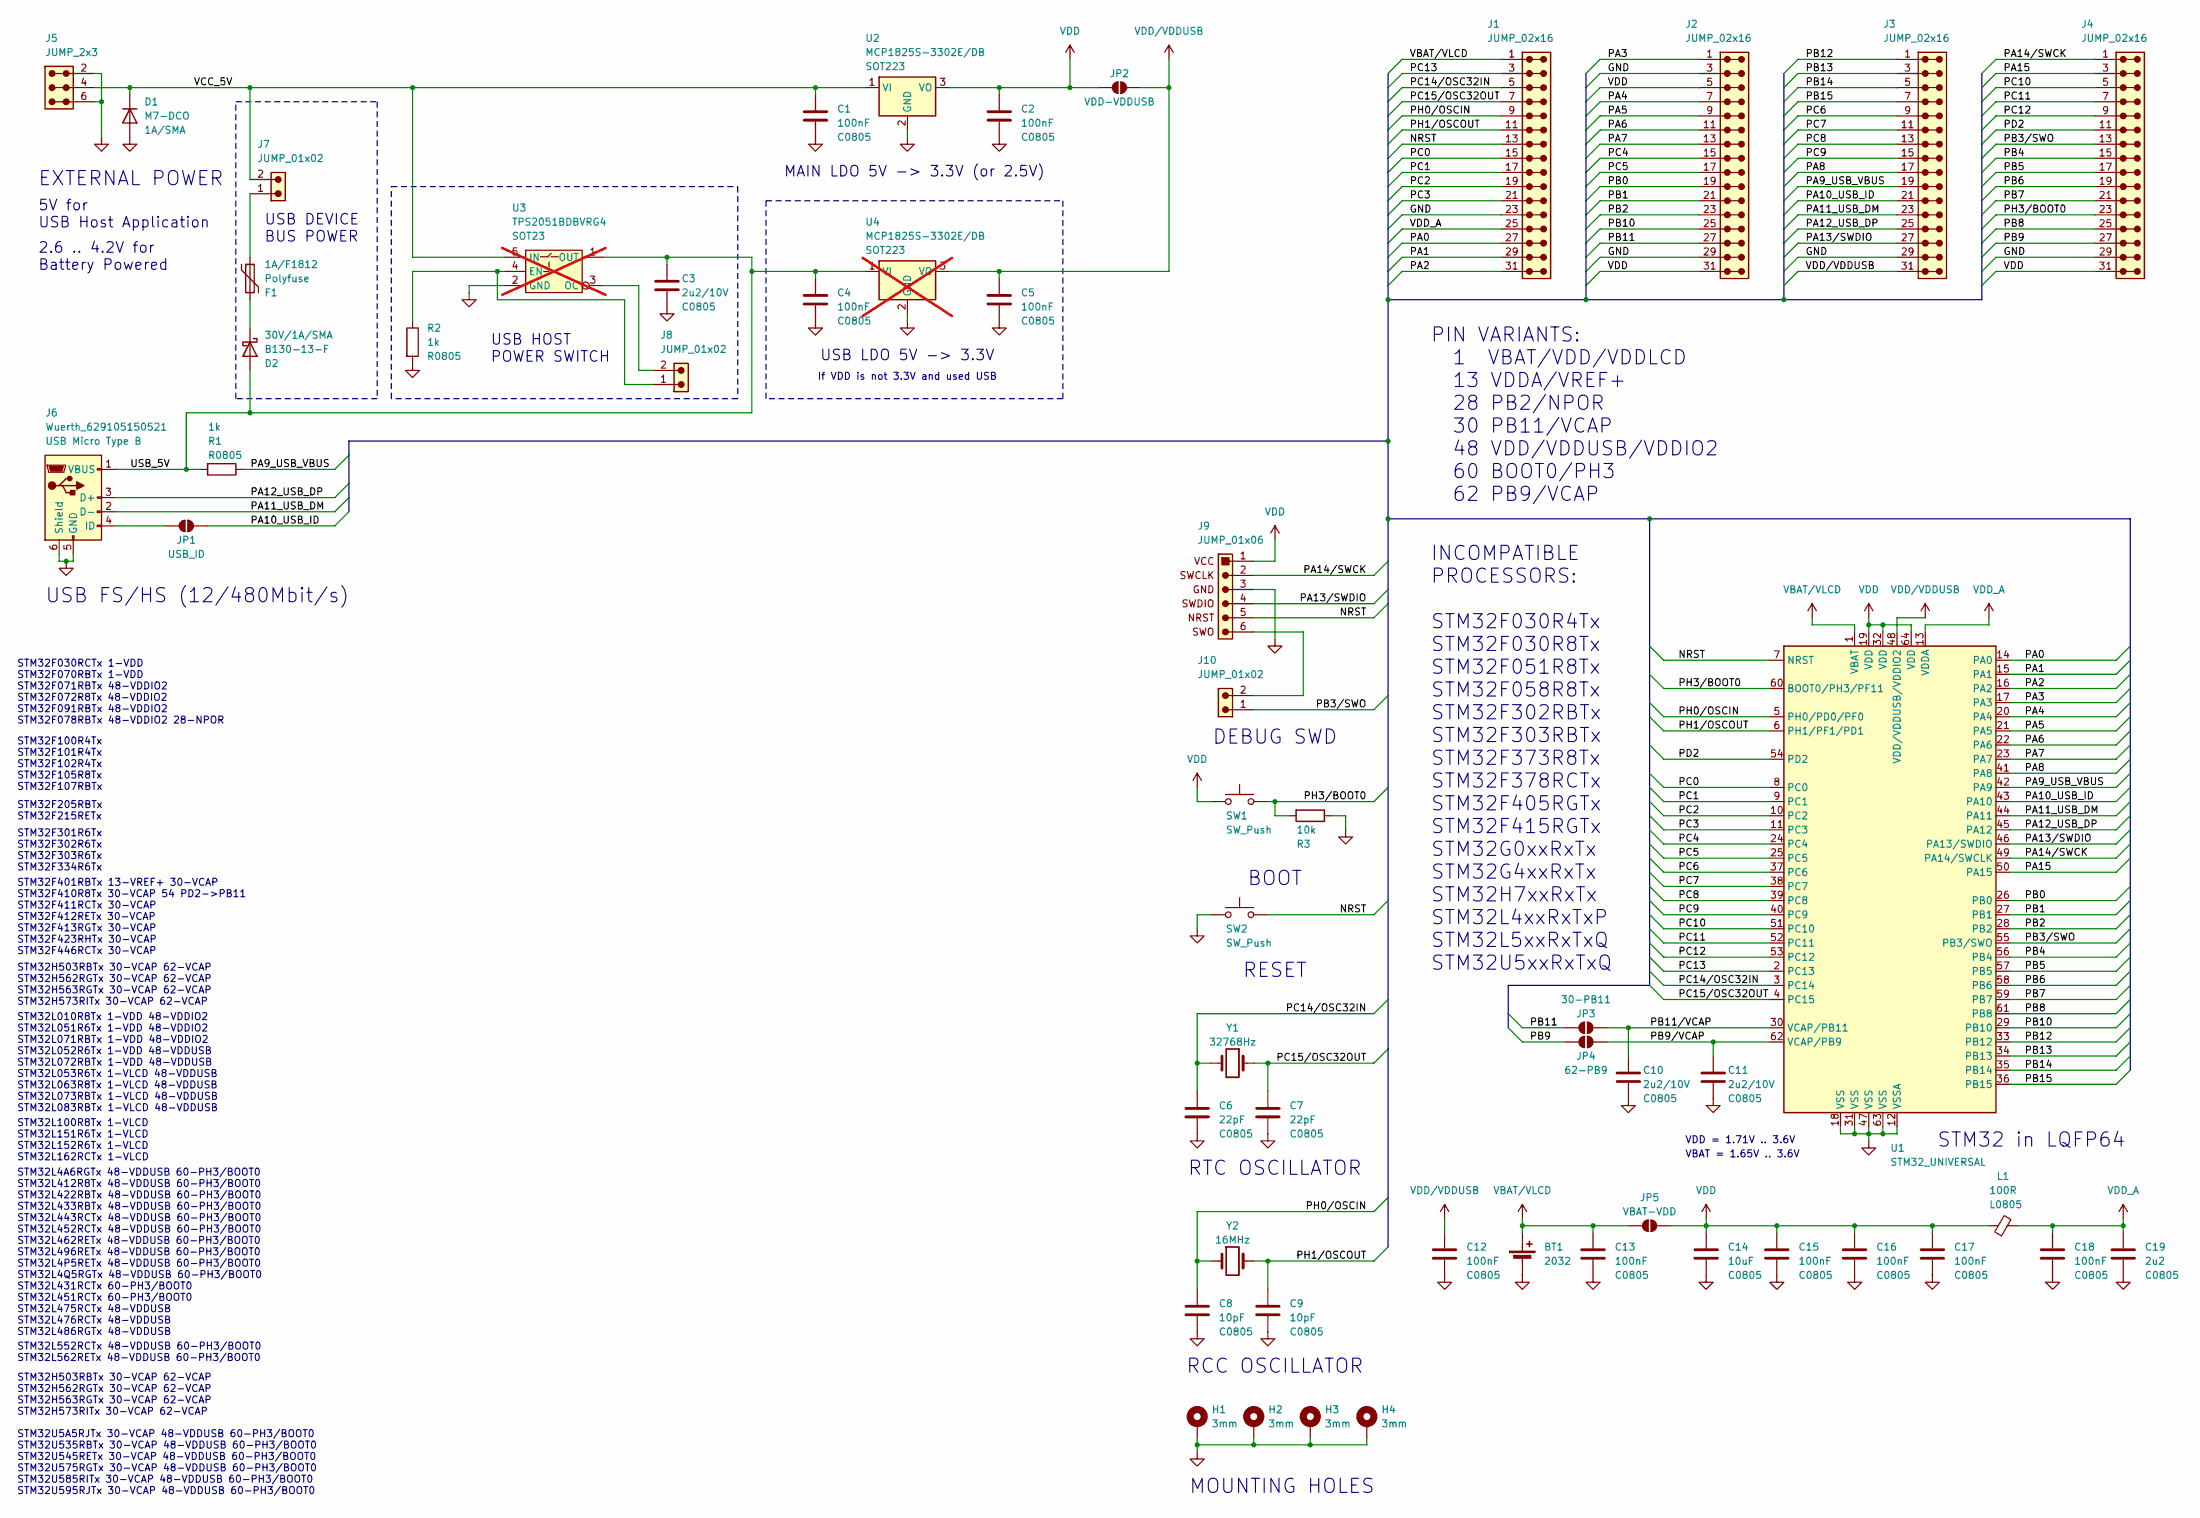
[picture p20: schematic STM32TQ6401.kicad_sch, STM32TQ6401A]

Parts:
BT1: 2032; BatteryHolder_Renata_SMTU2032
C1, C2, C4, C5, C12, C13, C15, C16, C17, C18: 100nF; C_0805_2012Metric_Pad1.18x1.45mm_HandSolder
C3, C10, C11: 2u2/10V; C_0805_2012Metric_Pad1.18x1.45mm_HandSolder
C6, C7: 22pF; C_0805_2012Metric_Pad1.18x1.45mm_HandSolder
C8, C9: 10pF; C_0805_2012Metric_Pad1.18x1.45mm_HandSolder
C14: 10uF; C_0805_2012Metric_Pad1.18x1.45mm_HandSolder
C19: 2u2; C_0805_2012Metric_Pad1.18x1.45mm_HandSolder
D1: M7-DCO; D_SMA_Handsoldering
D2: B130-13-F; D_SMA_Handsoldering
F1: Polyfuse; Fuse_1812_4532Metric_Pad1.30x3.40mm_HandSolder
H1, H2, H3, H4: 3mm; MountingHole_3.2mm_M3_DIN965_Pad
J1, J2, J3, J4: JUMP_02x16; PinHeader_2x16_P2.54mm_Vertical
J5: JUMP_2x3; PinHeader_2x03_P2.54mm_Vertical
J6: Wuerth_629105150521; USB_Micro-B_Wuerth_629105150521
J7, J8, J10: JUMP_01x02; PinHeader_1x02_P2.54mm_Vertical
J9: JUMP_01x06; PinHeader_1x06_P2.54mm_Vertical
JP1: USB_ID; SolderJumper-2_P1.3mm_Open_TrianglePad1.0x1.5mm
JP2: VDD-VDDUSB; SolderJumper-2_P1.3mm_Open_TrianglePad1.0x1.5mm
JP3: 30-PB11; SolderJumper-2_P1.3mm_Open_TrianglePad1.0x1.5mm
JP4: 62-PB9; SolderJumper-2_P1.3mm_Open_TrianglePad1.0x1.5mm
JP5: VBAT-VDD; SolderJumper-2_P1.3mm_Open_TrianglePad1.0x1.5mm
L1: 100R; L_0805_2012Metric_Pad1.15x1.40mm_HandSolder
R1, R2: 1k; C_0805_2012Metric_Pad1.18x1.45mm_HandSolder
R3: 10k; C_0805_2012Metric_Pad1.18x1.45mm_HandSolder
SW1, SW2: SW_Push; SW_PUSH_6mm
U1: STM32_UNIVERSAL; LQFP-64_10x10mm_P0.5mm
U2: MCP1825S-3302E/DB; SOT-223-3_TabPin2
U3: TPS2051BDBVRG4; SOT-23-5; not fitted
U4: MCP1825S-3302E/DB; SOT-223-3_TabPin2; not fitted
Y1: 32768Hz; Crystal_AT310_D3.0mm_L10.0mm_Horizontal
Y2: 16MHz; Crystal_HC49-U_Vertical

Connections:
/NRST: J1.13, J1.14, J9.5, SW2.2, U1.7 (NRST)
/PA0: J1.27, J1.28, U1.14 (PA0)
/PA1: J1.29, J1.30, U1.15 (PA1)
/PA2: J1.31, J1.32, U1.16 (PA2)
/PA3: J2.1, J2.2, U1.17 (PA3)
/PA4: J2.7, J2.8, U1.20 (PA4)
/PA5: J2.9, J2.10, U1.21 (PA5)
/PA6: J2.11, J2.12, U1.22 (PA6)
/PA7: J2.13, J2.14, U1.23 (PA7)
/PA8: J3.17, J3.18, U1.41 (PA8)
/PA9_USB_VBUS: J3.19, J3.20, R1.1, U1.42 (PA9)
/PA10_USB_ID: J3.21, J3.22, JP1.2 (B), U1.43 (PA10)
/PA11_USB_DM: J3.23, J3.24, J6.2 (D-), U1.44 (PA11)
/PA12_USB_DP: J3.25, J3.26, J6.3 (D+), U1.45 (PA12)
/PA13/SWDIO: J3.27, J3.28, J9.4, U1.46 (PA13/SWDIO)
/PA14/SWCK: J4.1, J4.2, J9.2, U1.49 (PA14/SWCLK)
/PA15: J4.3, J4.4, U1.50 (PA15)
/PB0: J2.19, J2.20, U1.26 (PB0)
/PB1: J2.21, J2.22, U1.27 (PB1)
/PB2: J2.23, J2.24, U1.28 (PB2)
/PB3/SWO: J4.13, J4.14, J10.1, U1.55 (PB3/SWO)
/PB4: J4.15, J4.16, U1.56 (PB4)
/PB5: J4.17, J4.18, U1.57 (PB5)
/PB6: J4.19, J4.20, U1.58 (PB6)
/PB7: J4.21, J4.22, U1.59 (PB7)
/PB8: J4.25, J4.26, U1.61 (PB8)
/PB9: J4.27, J4.28, JP4.1 (A)
/PB9/VCAP: C11.1, JP4.2 (B), U1.62 (VCAP/PB9)
/PB10: J2.25, J2.26, U1.29 (PB10)
/PB11: J2.27, J2.28, JP3.1 (A)
/PB11/VCAP: C10.1, JP3.2 (B), U1.30 (VCAP/PB11)
/PB12: J3.1, J3.2, U1.33 (PB12)
/PB13: J3.3, J3.4, U1.34 (PB13)
/PB14: J3.5, J3.6, U1.35 (PB14)
/PB15: J3.7, J3.8, U1.36 (PB15)
/PC0: J1.15, J1.16, U1.8 (PC0)
/PC1: J1.17, J1.18, U1.9 (PC1)
/PC2: J1.19, J1.20, U1.10 (PC2)
/PC3: J1.21, J1.22, U1.11 (PC3)
/PC4: J2.15, J2.16, U1.24 (PC4)
/PC5: J2.17, J2.18, U1.25 (PC5)
/PC6: J3.9, J3.10, U1.37 (PC6)
/PC7: J3.11, J3.12, U1.38 (PC7)
/PC8: J3.13, J3.14, U1.39 (PC8)
/PC9: J3.15, J3.16, U1.40 (PC9)
/PC10: J4.5, J4.6, U1.51 (PC10)
/PC11: J4.7, J4.8, U1.52 (PC11)
/PC12: J4.9, J4.10, U1.53 (PC12)
/PC13: J1.3, J1.4, U1.2 (PC13)
/PC14/OSC32IN: C6.1, J1.5, J1.6, U1.3 (PC14), Y1.2
/PC15/OSC32OUT: C7.1, J1.7, J1.8, U1.4 (PC15), Y1.1
/PD2: J4.11, J4.12, U1.54 (PD2)
/PH0/OSCIN: C8.1, J1.9, J1.10, U1.5 (PH0/PD0/PF0), Y2.1
/PH1/OSCOUT: C9.1, J1.11, J1.12, U1.6 (PH1/PF1/PD1), Y2.2
/PH3/BOOT0: J4.23, J4.24, R3.2, SW1.2, U1.60 (BOOT0/PH3/PF11)
/USB_5V: C3.1, C4.1, D2.2 (A), J6.1 (VBUS), R1.2, U3.1 (OUT), U4.1 (VI)
/VCC_5V: C1.1, D1.1 (K), J5.3, J5.4, J7.2, U2.1 (VI), U3.5 (IN)
GND: BT1.2 (-), C1.2, C2.2, C3.2, C4.2, C5.2, C6.2, C7.2, C8.2, C9.2, C10.2, C11.2, C12.2, C13.2, C14.2, C15.2, C16.2, C17.2, C18.2, C19.2, D1.2 (A), H1.1, H2.1, H3.1, H4.1, J1.23, J1.24, J2.3, J2.4, J2.29, J2.30, J3.29, J3.30, J4.29, J4.30, J5.1, J5.2, J5.5, J5.6, J6.5 (GND), J6.6 (Shield), J9.3, R2.2, R3.1, SW2.1, U1.12 (VSSA), U1.18 (VSS), U1.31 (VSS), U1.47 (VSS), U1.63 (VSS), U2.2 (GND), U3.2 (GND), U4.2 (GND)
unnamed: D2.1 (K), F1.2
unnamed: J6.4 (ID), JP1.1 (A)
unnamed: F1.1, J7.1
unnamed: J8.1, R2.1, U3.4 (EN)
unnamed: J8.2, U3.3 (OC)
unnamed: J9.6, J10.2
VDD: C2.1, C14.1, C15.1, C16.1, C17.1, J2.5, J2.6, J2.31, J2.32, J4.31, J4.32, J9.1, JP2.1 (A), JP5.2 (B), L1.1, SW1.1, U1.19 (VDD), U1.32 (VDD), U1.64 (VDD), U2.3 (VO)
VDD_A: C18.1, C19.1, J1.25, J1.26, L1.2, U1.13 (VDDA)

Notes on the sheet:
USB HOST POWER SWITCH
VDD = 1.71V .. 3.6V
STM32F401RBTx 13-VREF+ 30-VCAP STM32F410R8Tx 30-VCAP 54 PD2->PB11 STM32F411RCTx 30-VCAP STM32F412RETx 30-VCAP STM32F413RGTx 30-VCAP STM32F423RHTx 30-VCAP STM32F446RCTx 30-VCAP
STM32F301R6Tx STM32F302R6Tx STM32F303R6Tx STM32F334R6Tx
If VDD is not 3.3V and used USB
2.6 .. 4.2V for Battery Powered
STM32F100R4Tx STM32F101R4Tx STM32F102R4Tx STM32F105R8Tx STM32F107RBTx
STM32F205RBTx STM32F215RETx
RCC OSCILLATOR
USB DEVICE BUS POWER
STM32L010R8Tx 1-VDD 48-VDDIO2 STM32L051R6Tx 1-VDD 48-VDDIO2 STM32L071RBTx 1-VDD 48-VDDIO2 STM32L052R6Tx 1-VDD 48-VDDUSB STM32L072RBTx 1-VDD 48-VDDUSB STM32L053R6Tx 1-VLCD 48-VDDUSB STM32L063R8Tx 1-VLCD 48-VDDUSB STM32L073RBTx 1-VLCD 48-VDDUSB STM32L083RBTx 1-VLCD 48-VDDUSB
MAIN LDO 5V -> 3.3V (or 2.5V)
DEBUG SWD
MOUNTING HOLES
USB FS/HS (12/480Mbit/s)
USB LDO 5V -> 3.3V
5V for USB Host Application
STM32L4A6RGTx 48-VDDUSB 60-PH3/BOOT0 STM32L412R8Tx 48-VDDUSB 60-PH3/BOOT0 STM32L422RBTx 48-VDDUSB 60-PH3/BOOT0 STM32L433RBTx 48-VDDUSB 60-PH3/BOOT0 STM32L443RCTx 48-VDDUSB 60-PH3/BOOT0 STM32L452RCTx 48-VDDUSB 60-PH3/BOOT0 STM32L462RETx 48-VDDUSB 60-PH3/BOOT0 STM32L496RETx 48-VDDUSB 60-PH3/BOOT0 STM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
STM32U5A5RJTx 30-VCAP 48-VDDUSB 60-PH3/BOOT0 STM32U535RBTx 30-VCAP 48-VDDUSB 60-PH3/BOOT0 STM32U545RETx 30-VCAP 48-VDDUSB 60-PH3/BOOT0 STM32U575RGTx 30-VCAP 48-VDDUSB 60-PH3/BOOT0 STM32U585RITx 30-VCAP 48-VDDUSB 60-PH3/BOOT0 STM32U595RJTx 30-VCAP 48-VDDUSB 60-PH3/BOOT0
STM32L552RCTx 48-VDDUSB 60-PH3/BOOT0 STM32L562RETx 48-VDDUSB 60-PH3/BOOT0
PIN VARIANTS: 1 VBAT/VDD/VDDLCD 13 VDDA/VREF+ 28 PB2/NPOR 30 PB11/VCAP 48 VDD/VDDUSB/VDDIO2 60 BOOT0/PH3 62 PB9/VCAP
RESET
RTC OSCILLATOR
STM32F030RCTx 1-VDD STM32F070RBTx 1-VDD STM32F071RBTx 48-VDDIO2 STM32F072R8Tx 48-VDDIO2 STM32F091RBTx 48-VDDIO2 STM32F078RBTx 48-VDDIO2 28-NPOR
STM32H503RBTx 30-VCAP 62-VCAP STM32H562RGTx 30-VCAP 62-VCAP STM32H563RGTx 30-VCAP 62-VCAP STM32H573RITx 30-VCAP 62-VCAP
STM32 in LQFP64
BOOT
EXTERNAL POWER
INCOMPATIBLE PROCESSORS: STM32F030R4Tx STM32F030R8Tx STM32F051R8Tx STM32F058R8Tx STM32F302RBTx STM32F303RBTx STM32F373R8Tx STM32F378RCTx STM32F405RGTx STM32F415RGTx STM32G0xxRxTx STM32G4xxRxTx STM32H7xxRxTx STM32L4xxRxTxP STM32L5xxRxTxQ STM32U5xxRxTxQ
STM32L100R8Tx 1-VLCD STM32L151R6Tx 1-VLCD STM32L152R6Tx 1-VLCD STM32L162RCTx 1-VLCD
VBAT = 1.65V .. 3.6V

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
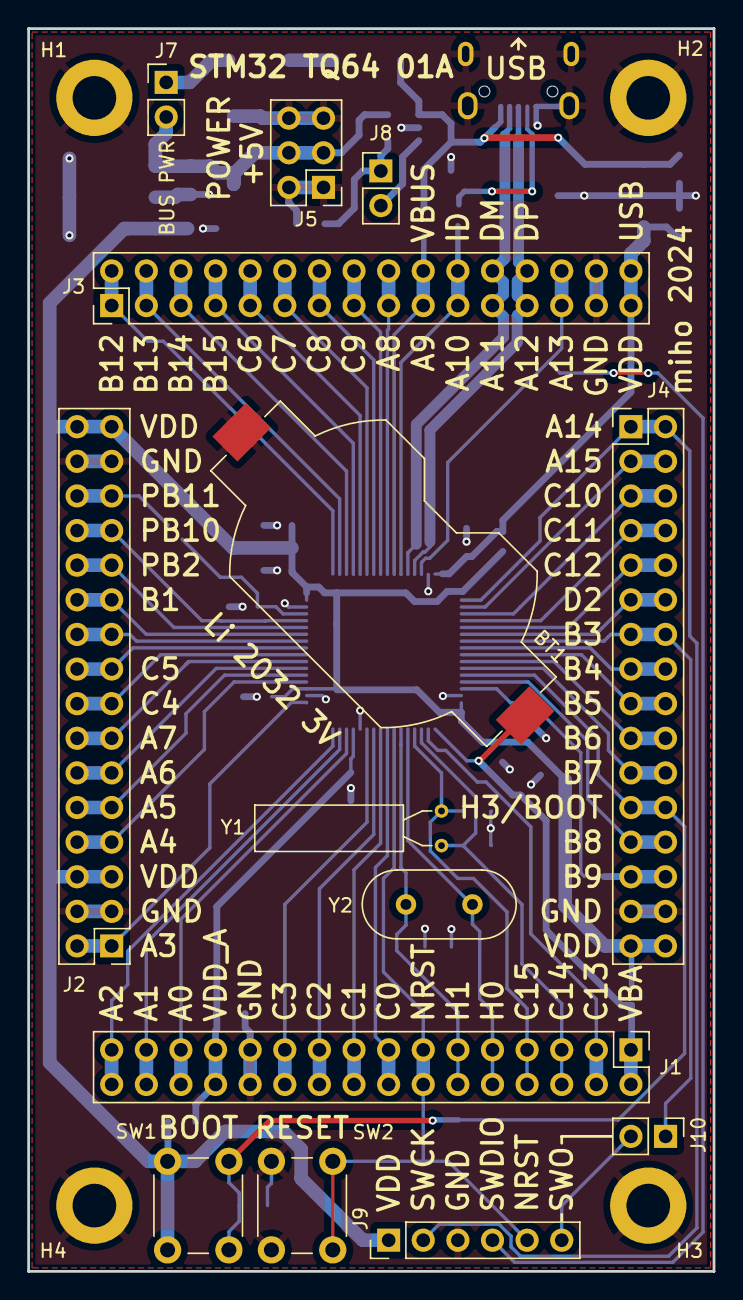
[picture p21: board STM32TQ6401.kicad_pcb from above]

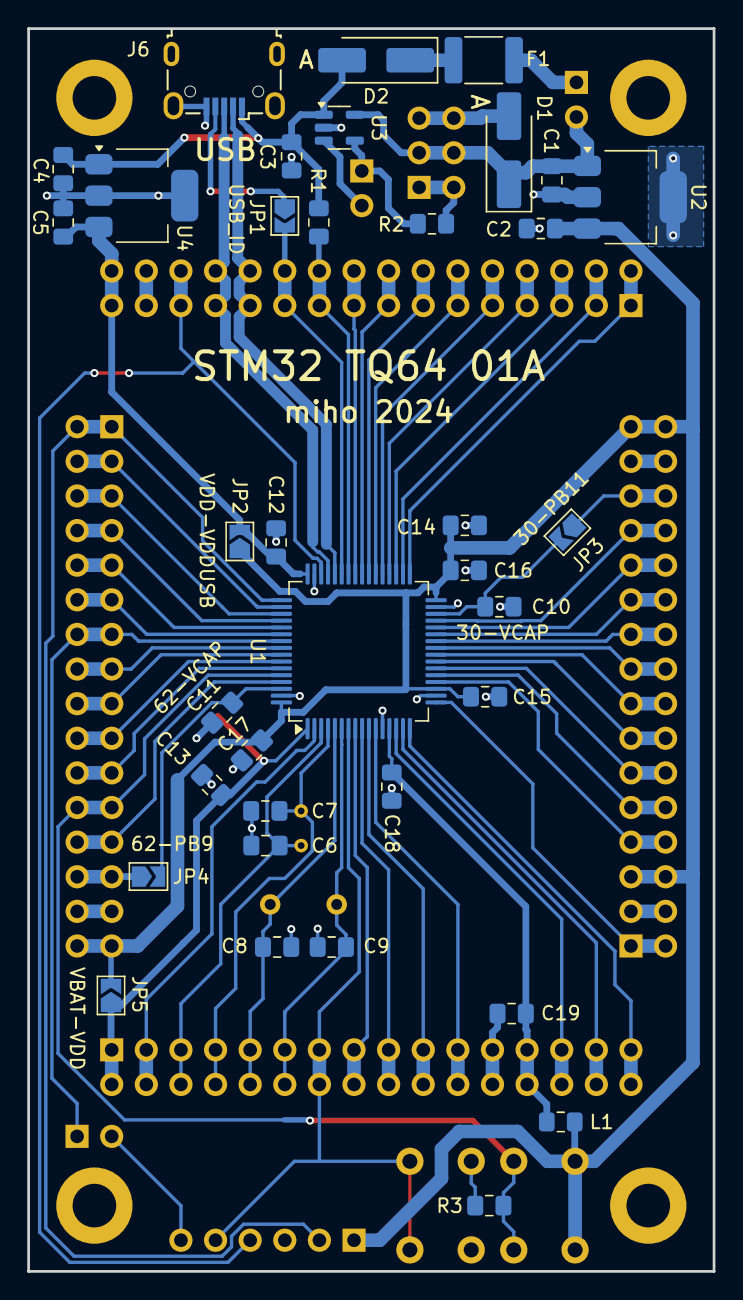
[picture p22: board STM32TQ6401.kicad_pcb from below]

Board: 2 copper layers, 50.3 x 91.2 mm, 54 parts (36 on the bottom side), 68 nets.

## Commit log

2025-03-22 Initial project from MIHO.
    [STM32TQ6401A.kicad_pcb, STM32TQ6401A.kicad_sch, STM32_Overview.kicad_pcb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]
2025-05-06 Update project description and metatadata.
    [STM32TQ6401A.kicad_pcb]
2025-05-06 Renaming project to get automatic action working.
    [STM32TQ6401.kicad_pcb, STM32TQ6401.kicad_sch]
2025-05-06 Update actions products
    [STM32TQ6401-B_Adhesive.dxf, STM32TQ6401-B_Courtyard.dxf, STM32TQ6401-B_Cu.dxf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]
